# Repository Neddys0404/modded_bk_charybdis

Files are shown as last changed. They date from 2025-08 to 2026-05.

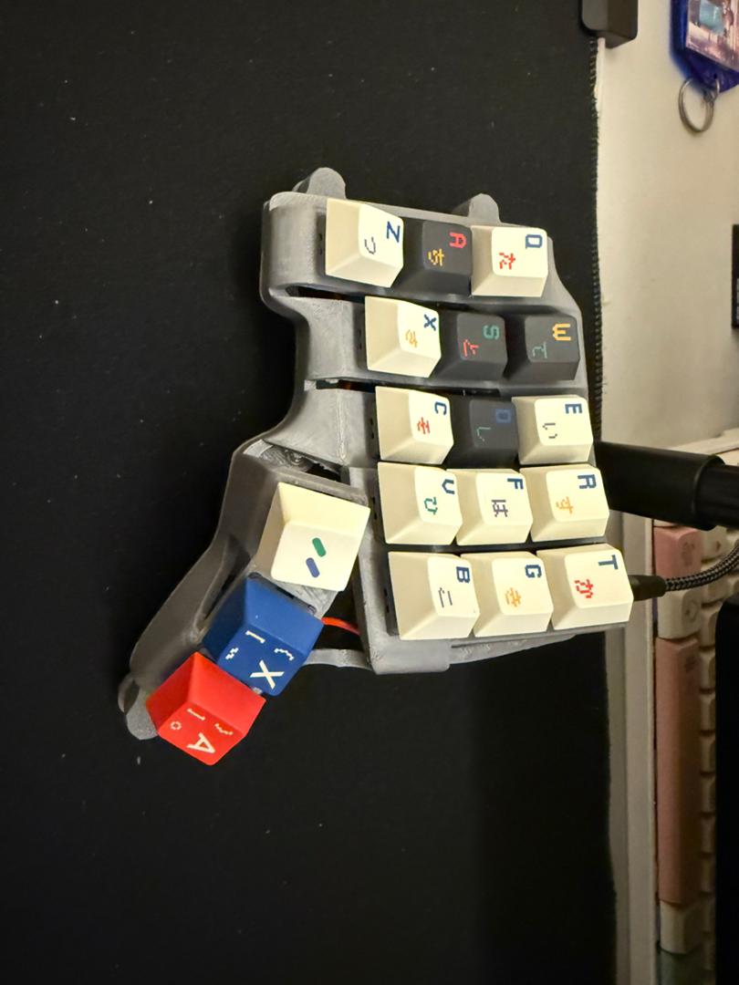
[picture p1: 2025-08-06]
images/LeftSide.jpg

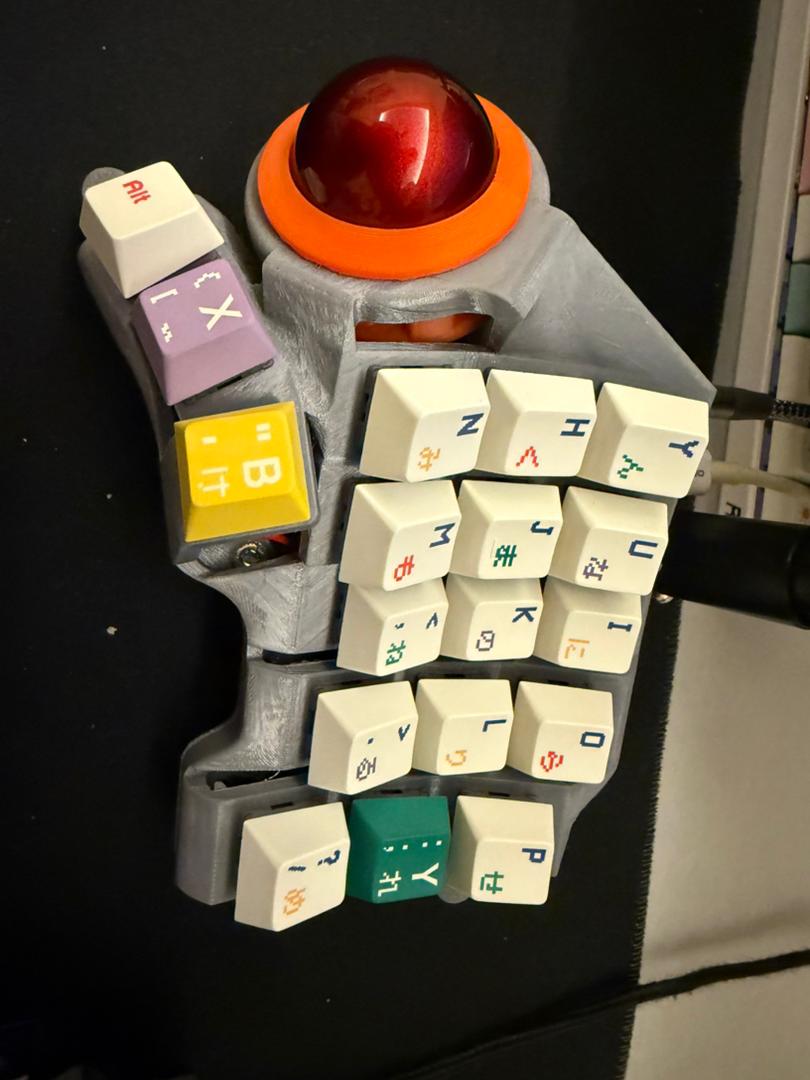
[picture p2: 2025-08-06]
images/RightSide.jpg

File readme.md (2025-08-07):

# modded_bk_charybdis

* Keyboard Maintainer: [ned](https://github.com/Neddys0404)
* MCU Supported: RP2040 Pro Micro
* MCU Availability: Aliexpress for the best price, but shopee (asia e-commerce platform) have some too
* Pointing Device Sensor: PMW3360
* Sensor Availability: Aliexpess only, shopee can't find.
* Switch used (Up to you): HMX Retros80 Game1989
* Original Keyboard Chassis Designer: [BastardKeyboard](https://bastardkb.com/)
* Keycaps: FBB SFC1990 from taobao

See the [build environment setup](https://docs.qmk.fm/#/getting_started_build_tools) and the [make instructions](https://docs.qmk.fm/#/getting_started_make_guide) for more information. Brand new to QMK? Start with our [Complete Newbs Guide](https://docs.qmk.fm/#/newbs).

## Bootloader

Enter the bootloader mode with 1 way ONLY:

* **Physical reset button**: Briefly press and hold the button on the back plate before connecting the power cable (USB), you will see a flash driving popping up in your PC, just copy and paste .uf2 firmware file into it and it will auto eject and reflash the firmware accordingly.

## Layout Customization

* Pre-requisite: QMK Knowledge, refer to their [documentations](https://docs.qmk.fm/#/getting_started_build_tools)
* If only modifying existing keys and macros, you only need to know basic programming language, Cpp, and how to compile the firmwares using QMK MSYS.

## Acoustic Considerations

* It will not have any hollow feel thanks to the thick chassis wall and stable tenting with stainless steel bolts
* Heavy Tactile may be too loud as any dampening measure beside o-ring mods that can dampen the sound is not available with this back plate.

## Bolts and Insert Nuts

* 16*M4 10mm countersunk for Back Plate Mounting with chassis, MCU holder mounting and sensor holder mounting with trackball holder.
* 8*M5 for Tenting (Length up to you, roughly measure it with your preference tenting angle)
* 2*M3 10mm Countersunk for mounting sensor cover
* 3*M3 10mm Button for mounting trackball's ball bearing
* 2 self-tapping screws or M3 bolts to mount sensor pcb in place

## Trackball Bearings

* 3*MR63 Ball Bearing

## Anti-Slip Pads

* Just buy some 1cm/10mm silicone pads from shopee or aliexpress
* 3D Printed Foots for attaching silicone pads are not in the repo (I drafted it and printed it whithin 5 mins, so i didnt save it)

## Matrix Connections (Direct Solder or with Switch Socket)

* If direct solder, hot-swap is not possible
* Switch socket used for this keyboard: Kailh MX Switch Socket, just search shopee.
* Some good soldering skills and good flux are required for both direct solder or switch socket.

*Any more information just dm me at @_dr_tay instagram. Dont email me.*

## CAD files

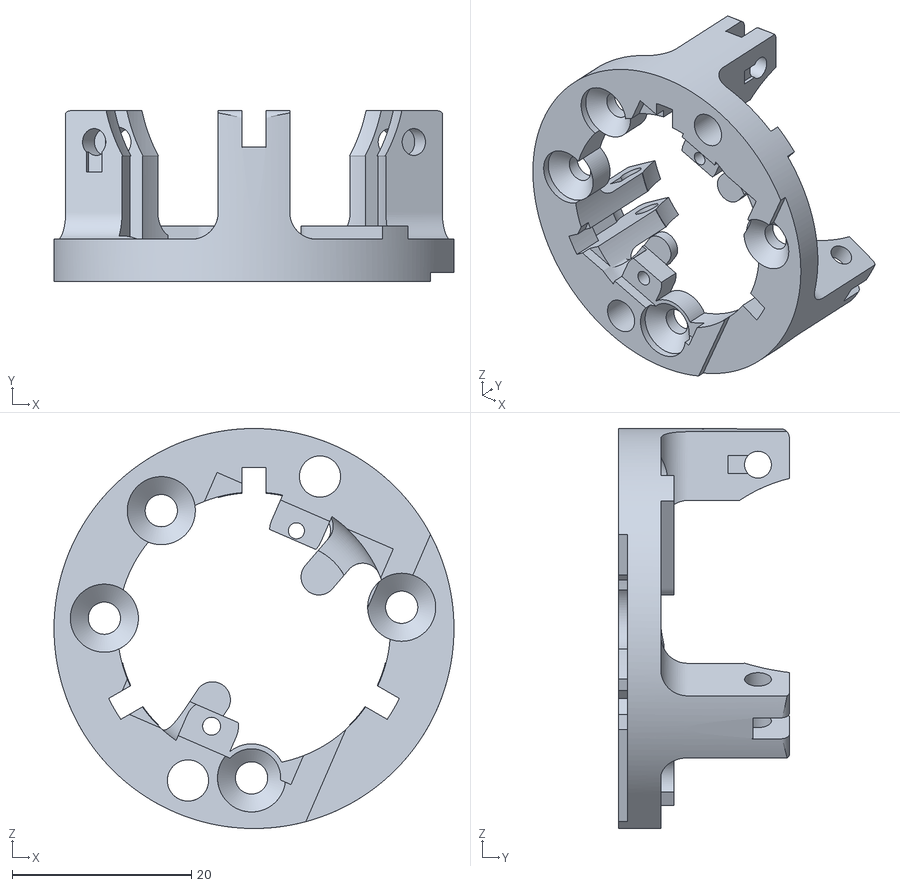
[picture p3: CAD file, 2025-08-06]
Printables/PMW_3360_Holder/Base_Type_One.stl
44.7 x 19.1 x 44.7

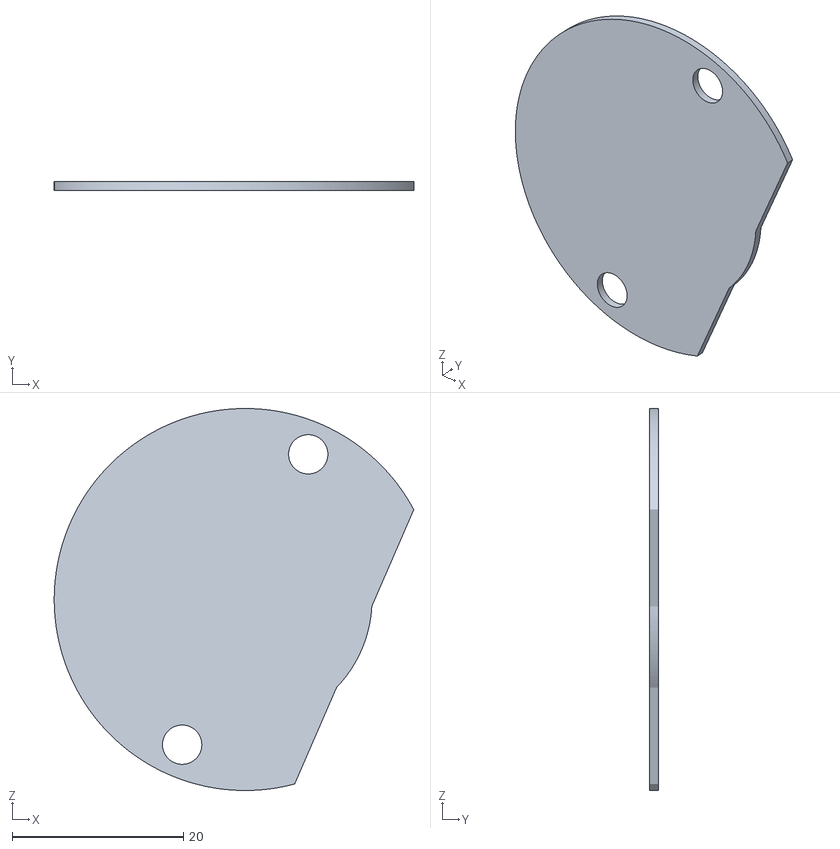
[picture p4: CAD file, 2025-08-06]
Printables/SensorCover.stl
42.0 x 1.00 x 44.6

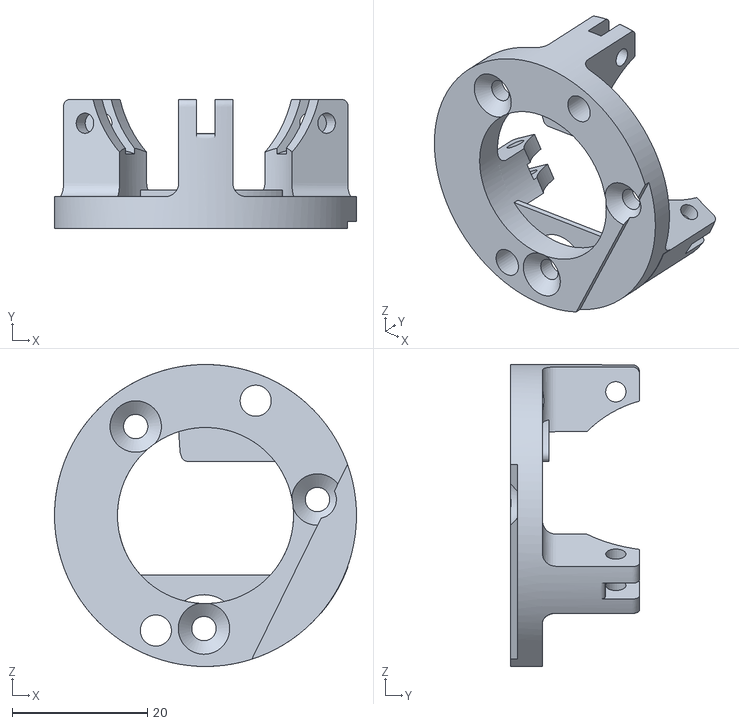
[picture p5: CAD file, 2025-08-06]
Printables/PMW_3360_Holder/Base_Type_Two.stl
44.6 x 19.1 x 44.6

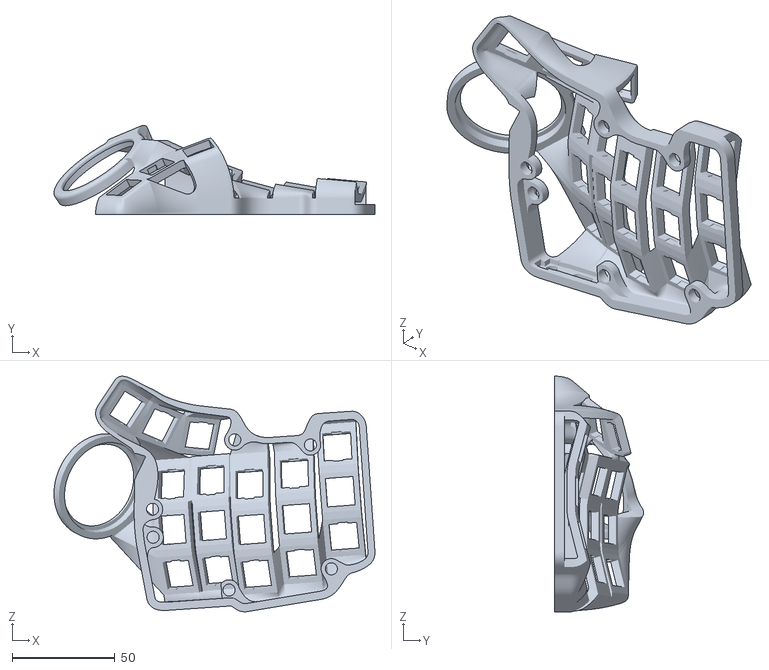
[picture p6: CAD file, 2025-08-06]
Printables/Right_Chassis.stl
156.6 x 43.5 x 114.9

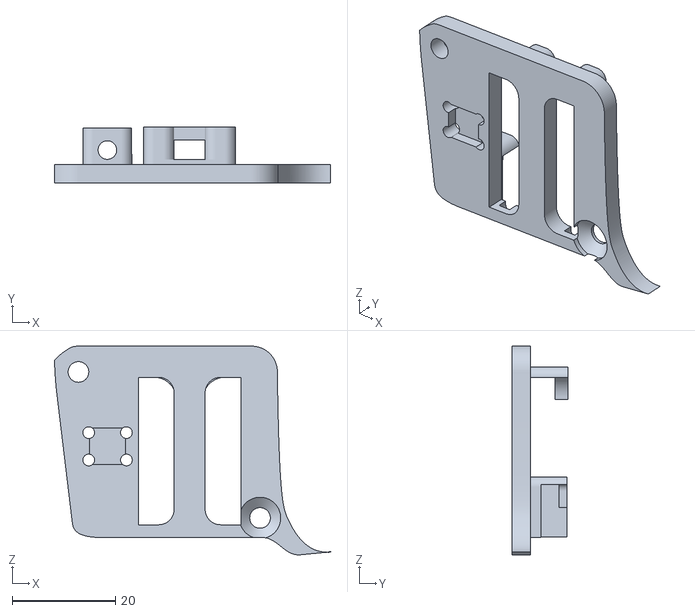
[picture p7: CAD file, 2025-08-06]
Printables/ProMicro_Holder.stl
53.4 x 10.9 x 40.4

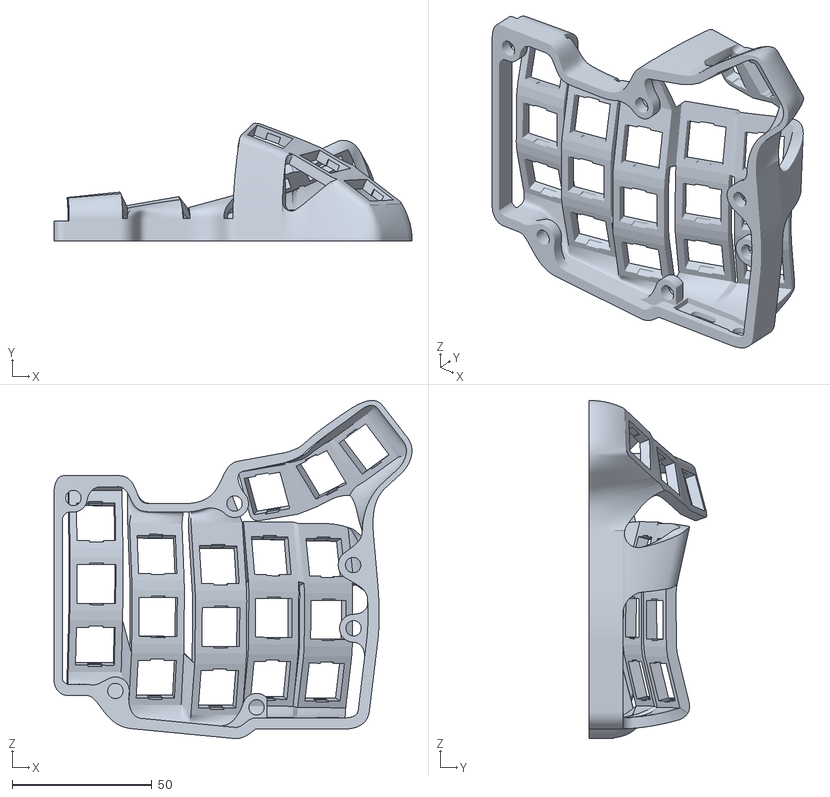
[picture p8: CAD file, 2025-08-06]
Printables/Left_Chassis.stl
128.0 x 42.0 x 120.9

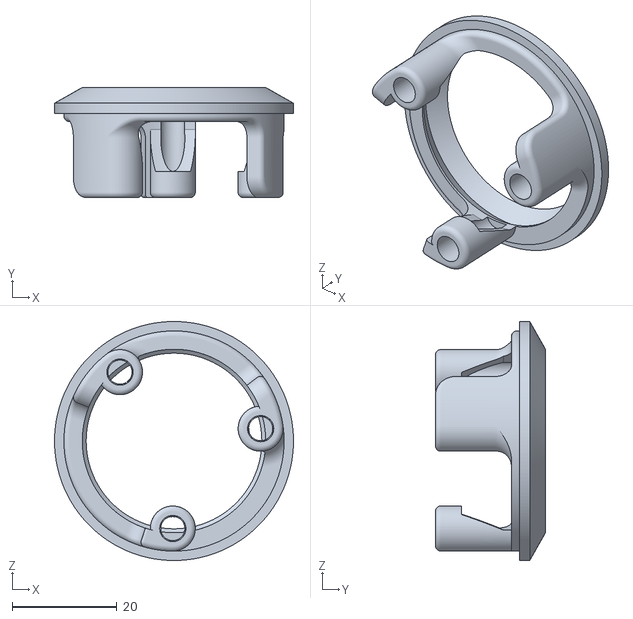
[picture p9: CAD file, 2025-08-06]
Printables/Ball_34mm_Mount.stl
45.6 x 21.0 x 45.6

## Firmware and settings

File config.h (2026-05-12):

#pragma once

#define DEBOUNCE 5

/* Handedness. */
#define SERIAL_USART_TX_PIN GP1

// Encoder Pins and resolutions
#define ENCODER_A_PINS { GP29 }
#define ENCODER_B_PINS { GP28 }
#define ENCODER_A_PINS_RIGHT { GP3 }
#define ENCODER_B_PINS_RIGHT { GP4 }
#define ENCODER_RESOLUTIONS_RIGHT 4
#define ENCODER_RESOLUTION 4

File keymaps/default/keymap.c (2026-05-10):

// Copyright 2023 QMK
// SPDX-License-Identifier: GPL-2.0-or-later

#include QMK_KEYBOARD_H

enum modded_charybdis_keymap_layers {
     LAYER_BASE = 0,
     LAYER_QUOTE,
     LAYER_NUM
};

enum custom_keys {
     AUTO_IF_P = SAFE_RANGE,
     AUTO_FOR_P,
     AUTO_WHILE_P,
     AUTO_CASE_P,
     AUTO_IF_C,
     AUTO_FOR_C,
     AUTO_WHILE_C,
     AUTO_CASE_C,
     SWITCH_TAB,
     OPEN_YT,
     OPEN_WS,
     OPEN_VSC,
     OPEN_PUTTY,
     OPEN_STEAM,
     OPEN_YTM,
     OPEN_FOLDER,
     SCREENSNIP,
};

#if defined(ENCODER_MAP_ENABLE)
const uint16_t PROGMEM encoder_map[][NUM_ENCODERS][NUM_DIRECTIONS] = {
    [LAYER_BASE] = { ENCODER_CCW_CW(MS_WHLU, MS_WHLD),  ENCODER_CCW_CW(KC_AUDIO_VOL_DOWN, KC_AUDIO_VOL_UP) },
    [LAYER_QUOTE] = { ENCODER_CCW_CW(KC_LEFT, KC_RIGHT),  ENCODER_CCW_CW(KC_AUDIO_VOL_DOWN, KC_AUDIO_VOL_UP) },
    [LAYER_NUM] = { ENCODER_CCW_CW(KC_LEFT, KC_RIGHT),  ENCODER_CCW_CW(KC_AUDIO_VOL_DOWN, KC_AUDIO_VOL_UP) },
};
#endif


#define QUOTE MO(LAYER_QUOTE)
#define NUM MO(LAYER_NUM)
#define MACRO MO(LAYER_MACRO)

#define SFT_Z SFT_T(KC_Z)
#define SFT_SLSH SFT_T(KC_SLSH)
#define GUI_SPC GUI_T(KC_SPC)
#define NUM_ENT LT(LAYER_NUM,KC_ENT)
#define QUOTE_BSPC  LT(LAYER_QUOTE,KC_BSPC)

bool process_record_user(uint16_t keycode, keyrecord_t *record) {
     switch (keycode) {
          case AUTO_IF_P:
               if (record->event.pressed) {
                    // when keycode QMKURL is pressed
                    SEND_STRING("if ():\n" SS_TAP(X_TAB));
               } else {
                    // when keycode QMKURL is released
               }
               break;
          case AUTO_FOR_P:
               if (record->event.pressed) {
                    // when keycode QMKURL is pressed
                    SEND_STRING("for i in range(len()):\n" SS_TAP(X_TAB));
               } else {
                    // when keycode QMKURL is released
               }
               break;
          case AUTO_WHILE_P:
               if (record->event.pressed) {
                    // when keycode QMKURL is pressed
                    SEND_STRING("while ():\n" SS_TAP(X_TAB));
               } else {
                    // when keycode QMKURL is released
               }
               break;
          case AUTO_IF_C:
               if   (record->event.pressed) {
                    // when keycode QMKURL is pressed
                    SEND_STRING("if () {\n\n\n\n}\n" SS_TAP(X_UP) SS_TAP(X_UP) SS_TAP(X_UP) SS_TAP(X_TAB));
               } else {
                    // when keycode QMKURL is released
               }
               break;
          case AUTO_FOR_C:
               if (record->event.pressed) {
                    // when keycode QMKURL is pressed
                    SEND_STRING("for (int i = 0; i < var.length; i++) {\n\n\n\n}\n" SS_TAP(X_UP) SS_TAP(X_UP) SS_TAP(X_UP) SS_TAP(X_TAB));
               } else {
                    // when keycode QMKURL is released
               }
               break;
          case AUTO_WHILE_C:
               if (record->event.pressed) {
                    // when keycode QMKURL is pressed
                    SEND_STRING("while () {\n\n\n\n}\n" SS_TAP(X_UP) SS_TAP(X_UP) SS_TAP(X_UP) SS_TAP(X_TAB));
               } else {
                    // when keycode QMKURL is released
               }
               break;

          case SWITCH_TAB:
               if (record->event.pressed) {
                    // when keycode QMKURL is pressed
                    SEND_STRING(SS_DOWN(X_LCTL) SS_DOWN(X_LSFT) SS_TAP(X_TAB) SS_UP(X_LCTL) SS_UP(X_LSFT));
               } else {
                    // when keycode QMKURL is released
               }
               break;

          case OPEN_YT:
               if (record->event.pressed) {
                    // when keycode QMKURL is pressed
                    SEND_STRING_DELAY(SS_LGUI("r"), 200);
                    SEND_STRING("chrome "); 
                    SEND_STRING("https://www.youtube.com"); 
                    SEND_STRING(SS_TAP(X_ENTER)); 
               } else {
                    // when keycode QMKURL is released
               }
               break;

          case OPEN_WS:
               if (record->event.pressed) {
                    // when keycode QMKURL is pressed
                    SEND_STRING(SS_LGUI("4")); //this requires whatsapp to be at first icon in the task bar 
               } else {
                    // when keycode QMKURL is released
               }
               break;

          case OPEN_VSC:
               if (record->event.pressed) {
                    // when keycode QMKURL is pressed
                    SEND_STRING_DELAY(SS_LGUI("r"), 200);
                    SEND_STRING("Code"); 
                    SEND_STRING(SS_TAP(X_ENTER)); 
               } else {
                    // when keycode QMKURL is released
               }
               break;

          case OPEN_PUTTY:
               if (record->event.pressed) {
                    // when keycode QMKURL is pressed
                    SEND_STRING_DELAY(SS_LGUI("r"), 200); 
                    SEND_STRING("PUTTY"); 
                    SEND_STRING(SS_TAP(X_ENTER)); 
               } else {
                    // when keycode QMKURL is released
               }
               break;

          case OPEN_STEAM:
               if (record->event.pressed) {
                    // when keycode QMKURL is pressed
                    SEND_STRING(SS_LGUI("1")); //this requires steam to be at first icon in the task bar
               } else {
                    // when keycode QMKURL is released
               }
               break;

          case OPEN_YTM:
               if (record->event.pressed) {
                    // when keycode QMKURL is pressed
                    SEND_STRING(SS_LGUI("2")); //this requires youtube music to be at second icon in the task bar
               } else {
                    // when keycode QMKURL is released
               }
               break;

          case OPEN_FOLDER:
               if (record->event.pressed) {
                    // when keycode QMKURL is pressed
                    SEND_STRING(SS_LGUI("3")); //this requires File Explorer to be at third icon in the task bar
               } else {
                    // when keycode QMKURL is released
               }
               break;

          case SCREENSNIP:
               if (record->event.pressed) {
                    // when keycode QMKURL is pressed
                    SEND_STRING_DELAY(SS_LGUI("r"), 200);
                    SEND_STRING("SnippingTool"); 
                    SEND_STRING(SS_TAP(X_ENTER)); 
               } else {
                    // when keycode QMKURL is released
               }
               break;
     }
     return true;
};
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

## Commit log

2025-08-06 added printables files and updated readme
    [Ball_34mm_Mount.stl, Base_Type_One.stl, Base_Type_Two.stl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]
2025-08-06 whatsapp macro bug fix
    [keymap.c]
2026-03-04 Implement encoder update for volume and page navigation
    Added encoder update function for volume and page navigation based on layer state. Removed unused scrolling functionality and related variables.
2026-03-04 Revert "Implement encoder update for volume and page navigation"
    This reverts commit 71f77320ff03fc8ee791b9edc03c8c7bab29434b.
    [keymap.c]
2026-03-04 removed trackball feature and added encoder feature, also modified and added gpios pins for additional keys
2026-03-04 bugfix wrong gpio naming
    [config.h]
2026-04-09 bugfix encoder definition in config.h
    bugfix keymap added if else statement to differentiate left or right split
    [config.h, keymap.c]
2026-04-09 updated pin allocation
2026-04-23 backup, added missing encoder definition for right side, bugfix extra layout index, converted from raw encoder function to mapping, added extra and mouse key
    [config.h, keymap.c]
2026-04-23 added missing handedness and serial pin allocation to enable serial split feature, buildable now but not yet tested
    [config.h]
2026-05-12 updated rules to use EE hands so no need handedness pin
2026-05-12 bugfix gpio pin allocation and used EE hands instead
